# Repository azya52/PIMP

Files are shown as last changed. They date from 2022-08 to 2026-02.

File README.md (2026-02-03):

# PIMP
Модуль памяти для "Электроника МК-90" на основе отладочной платы Raspberry Pi Pico.

**Возможности:**
- Простое копирование образов картриджей - при подключении к ПК модуль работает как флешка (1,8МБ);
- При подключении к МК-90 модуль монтирует autorun.bin или первый попавшийся образ и работает как обычный МПО/СМП (только на чтение);
- Поддержка (только на чтение) протокола [Genjitsu SMP](https://github.com/vladkorotnev/SMPEmu/tree/master/pdp) благодаря чему можно загрузить несколько образов и выбирать нужный из списка непосредственно на МК90.

**Что понадобится:**
- Сама отладочная плата Raspberry Pi Pico;
- Преобразователь логических уровней 4-х канальный (стоит копейки);
- Тактовая кнопка (для сброса смонтированного образа).

**Схема подключения:**

Красивая:
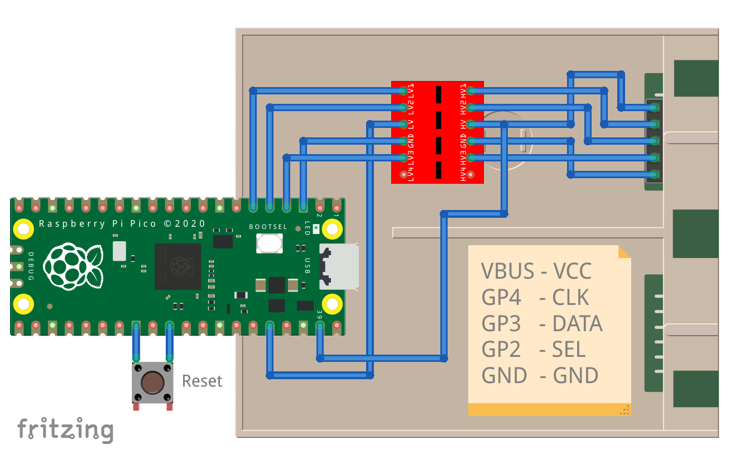
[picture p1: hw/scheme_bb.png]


Понятная:
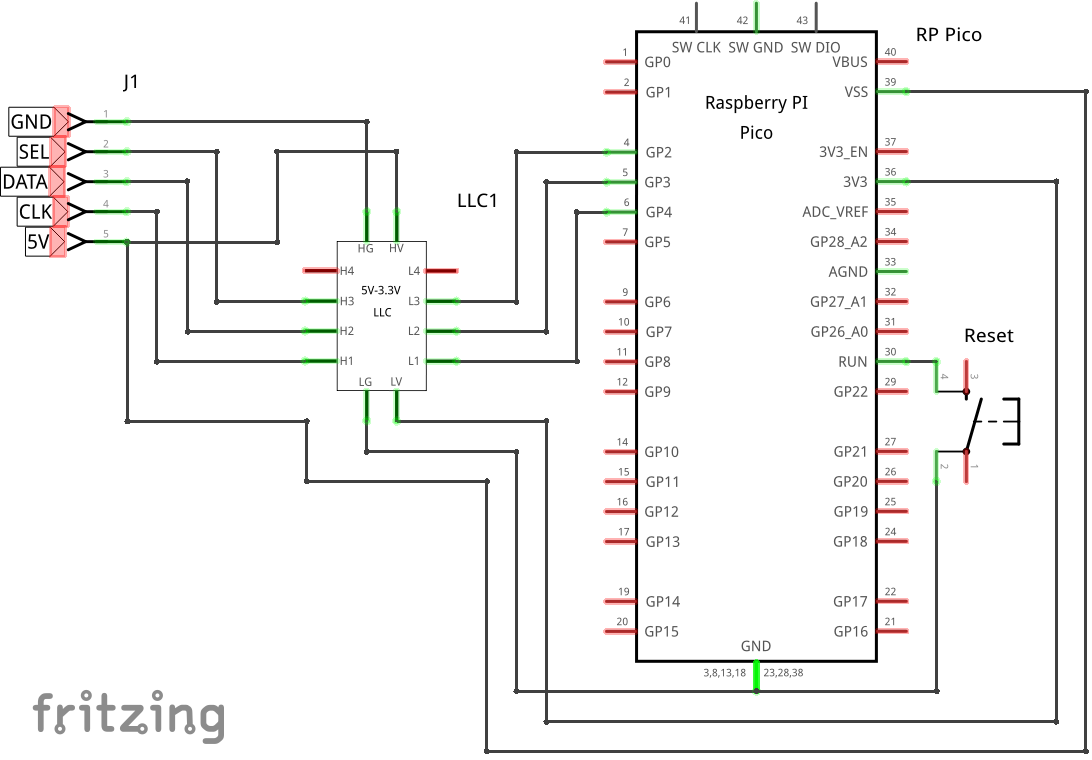
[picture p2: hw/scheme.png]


Для начала, нужно прошить Pico - для этого надо зажать единственную кнопку на плате, не отпуская ее подключить к ПК, плата определится как накопитель, на который копируем [pimp.uf2](/build/pimp.uf2). На этом прошивка закончена, модуль начнет определяться как Mass Storage Device, его нужно отформатировать в FAT с дефолтными параметрами, в итоге получится "флешка" на ~1,80МБ, на которую можно копировать образы. Если модуль отформатировался нормально и на него скопирован какой-либо образ, можно подключать его к МК-90 по указанной выше схеме.

Cхема относительно простая, хотя и есть одна проблема - МК-90 не любит нагрузку в выключенном состоянии (а при лучшем варианте Pico потребляет ~700мкА) поэтому, при разряженных батарейках, с подлюченным PIMP, МК-90 может не запускаться.

**Мультикартридж**

Для возможности выбора образа из нескольких непосредственно на МК-90, достаточно скопировать на модуль [загрузчик](https://github.com/vladkorotnev/SMPEmu/blob/master/pdp/autorun.bin) и конечно скопировать нужные образы.

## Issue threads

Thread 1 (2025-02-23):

Недочеты в PIMP

Bs0Dd, 2025-02-23:
Добрались у меня руки и до PIMP. Собрал себе в итоге два картриджа.

Первое с чем случилась пробема - с оригинальной схемой PIMP у меня глючил. Судя по всему, не хватало напряжения. По регламенту в МК90 на питание картриджа выдается 5в, в перерисовках петра указано 4.8. У меня же де-факто 4.5-4.6.
Не знаю, неисправность ли это (полупроводники уже могут быть "не те"), или так с завода. Сам по себе МК спокойно работает.

Проблема ушла при питании Pico от внешнего источника, но вот после десятка перетыканий между МК и ПК модуль Pico взял и выгорел (кз по питанию). Второй модуль вскоре аналогичным образом постигла та же учесть. Видимо диодно-резисторный согласователь такое не допускает (не эксперт - не знаю).

В итоге купил себе пару платок логических преобразователей (4 канальные) и собрал на них.
И от МК90 все работает (даже два модуля сразу), и сбоев никаких нет, да и компактнее вышло.

https://youtu.be/LFA96dhfLsM

Но, обнаружилась пара странных проблем, смахивающих уже на программные:

1. Монтирование образов (через Genjitsu) вызывает сбои, если на модуле больше 4 файлов (загрузчик + 3 образа). Стоит удалить любой "лишний" файл (чтобы их снова стало 4), монтирование начинает исправно работать. Добавляем 1 файл - после перезагрузки (когда указано имя файла) загорается светодиод ("ошибка"). Возможно что-то не так с драйвером ФС.
2. Если загрузить сборник Цветотроновских игр, с него не удается запустить игры/обучалки с последней страницы обоих списков. Такое ощущение, что после отгрузки этих последних страниц в эмуляторе происходит ошибка. После этого если вернуться в главное меню - не удастся открыть ни один из списков (сразу звуковой сигнал и возврат в меню), а если вернуться в меню загрузки - с СМП уже не получится загрузиться. Но что странно, светодиод ошибки при этом не горит...

Ну и еще проблема, очевидно, не связанная с эмулятором, но хотелось бы уточнить, не у одного ли у меня так.
Если запускать Цветотроновские игры со сборника, то в те моменты, когда у звука должна быть пауза, вместо нее присутствует какое-то странное жужжание в динамике. При этом если те же игры запустить с раздельных образов от Петра, жужжания нет. Может конечно дело в том, что сборник рассчитан на систему с BASIC 2.0, и лезет к какой-то системной подпрограмме, а у 1.0 не совсем те адреса, и Петр в раздельных образах это поправил...

https://youtu.be/3ItyVBS-i8Q

Bs0Dd, 2025-02-26:
Ну вот у меня почему-то никак не хочет больше 4 файлов нормально обрабатывать.
https://youtu.be/4b7dEg6dZbM

STMP бы попробовать, но с ним вот тоже возникли неполадки, issue оставлял еще перед этим.

Кстати, известо ли как частота обновления экрана задается? У Петра этот регистр толком не описан, в эмуляторе соответственно тоже не реализован.

azya52, 2025-02-27:
Постараюсь на днях проверить.
Частота задается через регистр $E802 описанный в таблице 2 даташита - https://web.archive.org/web/20200929094034/http://www.pisi.com.pl/piotr433/manuals/1835vg3.htm

Bs0Dd, 2025-03-26:
Нашел причину проблем с Цветотроновским сборником.
Перед отображением каждой страницы каталога и разных частей памяти вычитываются, видимо, заголовки (особо не вникал, для дела не важно).
И как раз при вычитке последних страниц каталогов (что у игр, что у обучашек) алгоритм чтения пытается вычитать диапазон 0x30000-0x30050, а картридж кончается на 0x2FFFF.

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

Для оригинального СМП это конечно не проблема, он (по идее) просто будет отдавать FF, но у PIMP, кажется, нет проверки на выход за границы образа - вот его и "накрывает". Если расширить образ, дописав в конец FF или 00, проблема исчезает и программы с последних страниц каталогов успешно загружаются.

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

Насчет жужжания в паузах при проигрывании музыки: оказывается там немного более веселая ситуация, но Петр действительно патчил игры при разделении их на образы к МПО-10. Я применил эти патчи в образ сборника и проблема исчезла, надо будет выложить его, как еще пару полезных патчей оттестирую.

P.S. писал пару дней назад на почту по поводу пары других проблем. В том числе с Птичкой на PIMP. Когда модуль вставлен в нулевой отсек, после загрузки игры загорается индикатор ошибки и модуль надо перевставлять. При первом отсеке такой проблемы нет. Пока не выяснял, в чем причина, но видимо после загрузки (загорается примерно сразу с появлением заставки) посылается какой-то неправильный запрос в СМП.

Bs0Dd, 2025-04-17:
Проблема с монтированием образов действительно оказалась НЕ связана с PIMP.

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

Загрузчик Genjitsu при передаче пути тестировал на нуль не байт, а слово, поэтому, перескакивал через него и продолжал транслировать ошметки загруженного списка файлов (буфер на все один), что, видимо и приводило к ошибке в СМП. А поскольку чем больше файлов, тем длиннее список и тем больше передается мусора, видимо это и влияло на сбои.

Переработал загрузчик (и в добавок написал софт для программирования оригинальных МПО-10 с помощью PIMP/STMP), поисправлял другие косячки, недочеты, добавил пару фишек. Проблема меня более не преследует.

Все остальное остается актуальным (касаемо сбоя со сборником игр и птичкой).

Насчет птички:

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

Похоже что этот кусок кода провоцирует отправку команды 0 на нулевой слот СМП, и если на нем находится PIMP (даже если игру запустить с МПО-10 в первом слоте), он эту команду считает за некорректную и уходит в состояние ошибки. Не вникал для чего именно он нужен, но в идеале бы тогда в неотладочной прошивке сделать игнор невалидных для PIMP команд (подобно ВГ2), вместо зацикливания в ошибке.

azya52, 2025-05-01:
Извините, что опять пропал - тяжело вернутся к проекту который уже отпустил) Теперь понятно почему я не ловил эту ошибку - я обычно переименовывал название образов в 1-2 буквы чтобы долго не печатать. Я постараюсь все же заставить себя и разобраться с этими ошибками. Спасибо за проделанную работу!

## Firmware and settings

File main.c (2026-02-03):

#include "tusb.h"
#include "fatfs/ff.h"
#include "main.h"
#include "stdlib.h"
#include "hardware/pll.h"
#include "hardware/clocks.h"
#include "hardware/structs/xip_ctrl.h"
#include "hardware/structs/syscfg.h"
#include "hardware/adc.h"
#include "hardware/rosc.h"
#include "hardware/xosc.h"
#include "mk90.pio.h"

FATFS FATFS_Obj;
FIL	appFile;
char fileList[256][12+1];
uint8_t	readBuffer;
PIO pio;
uint32_t sm_tx;
uint32_t sm_rx;

static void pio_irq(void);

static void error_handler(void) {
    while(1) {
        gpio_xor_mask(0x01 << PIN_LED);
        busy_wait_ms(255);
	}
}

static void clocks_initialize(void) {  
    // Enable the xosc
    xosc_init();

    // Before we touch PLLs, switch sys and ref cleanly away from their aux sources.
    hw_clear_bits(&clocks_hw->clk[clk_sys].ctrl, CLOCKS_CLK_SYS_CTRL_SRC_BITS);
    while (clocks_hw->clk[clk_sys].selected != 0x1) tight_loop_contents();

    pll_init(pll_usb, 1, 768 * MHZ, 4, 4);
    pll_deinit(pll_sys);

    clock_configure(clk_sys,
                    CLOCKS_CLK_SYS_CTRL_SRC_VALUE_CLKSRC_CLK_SYS_AUX,
                    CLOCKS_CLK_SYS_CTRL_AUXSRC_VALUE_CLKSRC_PLL_USB,
                    48 * MHZ,
                    48 * MHZ);

    clock_configure(clk_usb,
                    0, // No GLMUX
                    CLOCKS_CLK_USB_CTRL_AUXSRC_VALUE_CLKSRC_PLL_USB,
                    48 * MHZ,
                    48 * MHZ);

    clock_configure(clk_adc,
                    0, // No GLMUX
                    CLOCKS_CLK_ADC_CTRL_AUXSRC_VALUE_CLKSRC_PLL_USB,
                    48 * MHZ,
                    48 * MHZ);

    clock_stop(clk_ref);
    clock_stop(clk_peri);
    clock_stop(clk_rtc);
    clock_stop(clk_gpout0);
    clock_stop(clk_gpout1);
    clock_stop(clk_gpout2);
    clock_stop(clk_gpout3);

    clocks_hw->wake_en0 = ~(
        //CLOCKS_WAKE_EN0_CLK_SYS_VREG_AND_CHIP_RESET_BITS |
        CLOCKS_WAKE_EN0_CLK_SYS_RESETS_BITS |
        CLOCKS_WAKE_EN0_CLK_SYS_SPI0_BITS |
        CLOCKS_WAKE_EN0_CLK_PERI_SPI0_BITS |
        CLOCKS_WAKE_EN0_CLK_SYS_SPI1_BITS |
        CLOCKS_WAKE_EN0_CLK_PERI_SPI1_BITS |
        CLOCKS_WAKE_EN0_CLK_SYS_ROSC_BITS |
        CLOCKS_WAKE_EN0_CLK_SYS_PLL_SYS_BITS |
        CLOCKS_WAKE_EN0_CLK_SYS_PWM_BITS |
        CLOCKS_WAKE_EN0_CLK_SYS_PIO1_BITS |
        CLOCKS_WAKE_EN0_CLK_SYS_JTAG_BITS |
        CLOCKS_WAKE_EN0_CLK_SYS_I2C0_BITS |
        CLOCKS_WAKE_EN0_CLK_SYS_I2C1_BITS |
        CLOCKS_WAKE_EN0_CLK_SYS_RTC_BITS |
        CLOCKS_WAKE_EN0_CLK_RTC_RTC_BITS |
        CLOCKS_WAKE_EN0_CLK_SYS_DMA_BITS
    );

    clocks_hw->wake_en1 = ~(
        CLOCKS_WAKE_EN1_CLK_SYS_WATCHDOG_BITS |
        CLOCKS_WAKE_EN1_CLK_SYS_UART0_BITS |
        CLOCKS_WAKE_EN1_CLK_PERI_UART0_BITS |
        CLOCKS_WAKE_EN1_CLK_SYS_UART1_BITS |
        CLOCKS_WAKE_EN1_CLK_PERI_UART1_BITS |
        CLOCKS_WAKE_EN1_CLK_SYS_TBMAN_BITS |
        CLOCKS_WAKE_EN1_CLK_SYS_TIMER_BITS |
        CLOCKS_WAKE_EN1_CLK_SYS_SYSINFO_BITS
    );
    
}

static void dormant_goto_and_comeback(void) {
    uint32_t intstatus = save_and_disable_interrupts();
    gpio_set_dormant_irq_enabled(PIN_SELECT, IO_BANK0_DORMANT_WAKE_INTE0_GPIO0_EDGE_LOW_BITS, true);

    // Turn off flash
    xip_ctrl_hw->ctrl |= XIP_CTRL_POWER_DOWN_BITS;
    // Turn off SRAMs
    syscfg_hw->mempowerdown =
        0x00000020 | //SRAM5
        0x00000010 | //SRAM4
        0x00000080 | //USB
        0x00000040; //ROM

    // Before we touch PLLs, switch sys and ref cleanly away from their aux sources.
    hw_clear_bits(&clocks_hw->clk[clk_sys].ctrl, CLOCKS_CLK_SYS_CTRL_SRC_BITS);
    while (clocks_hw->clk[clk_sys].selected != 0x1) tight_loop_contents();
    pll_deinit(pll_sys);
    pll_deinit(pll_usb);

    // Sleep
    xosc_dormant();

    // Turn on SRAMs
    syscfg_hw->mempowerdown = 0;
    // Turn on flash
    xip_ctrl_hw->ctrl &= ~XIP_CTRL_POWER_DOWN_BITS;
    // Clear the irq so we can go back to dormant mode again if we want
    gpio_acknowledge_irq(PIN_SELECT, IO_BANK0_DORMANT_WAKE_INTE0_GPIO0_EDGE_LOW_BITS);
    // Restore clocks
    clocks_initialize();
    restore_interrupts(intstatus);
}

static void adc_irq(void) {
    uint16_t value = adc_fifo_get();
    if ((value > 0) && (value < ADC_4V2_THRESH)) {
        dormant_goto_and_comeback();
    }
}

static inline void adc_initialize(void) {
    adc_init();
	adc_gpio_init(29);
	adc_select_input(3);	// start with measurement for GPIO29 - IP Used in ADC mode (ADC3) to measure VSYS/3
	adc_fifo_setup(true, false, 1, true, false);
	irq_set_exclusive_handler(ADC_IRQ_FIFO, adc_irq);
	adc_irq_set_enabled(true);
	irq_set_enabled(ADC_IRQ_FIFO, true);
    irq_set_priority(ADC_IRQ_FIFO, PICO_LOWEST_IRQ_PRIORITY);
	adc_set_clkdiv(65535);	// slowest possible 65535: 832 measurements / sec
	adc_run(true);
}

static inline void gpio_initialize(void) {
    gpio_pull_up(PIN_CLK);
    gpio_pull_up(PIN_SELECT);
    gpio_pull_up(PIN_DATA);

    gpio_init(PIN_SELECT);
    gpio_init(PIN_VBUS);
    gpio_init(PIN_LED);

    gpio_set_dir(PIN_VBUS, GPIO_IN);
    gpio_set_dir(PIN_LED, GPIO_OUT);
    gpio_set_dir(PIN_SELECT, GPIO_IN);
}

static inline void pio_initialize(void) {
    pio = pio0;
    sm_tx = pio_claim_unused_sm(pio, true);
    sm_rx = pio_claim_unused_sm(pio, true);
    mk90bus_program_init(pio, sm_tx, sm_rx);
    
    irq_set_exclusive_handler(PIO0_IRQ_0, pio_irq);
    irq_set_enabled(PIO0_IRQ_0, true);
    pio_set_irq0_source_enabled(pio, pis_sm1_rx_fifo_not_empty, true);
    irq_set_priority(PIO0_IRQ_0, PICO_HIGHEST_IRQ_PRIORITY);
}

FRESULT openFile(char *filename) {
    DIR dj;
    FILINFO fno;
    FRESULT fr;

    f_close(&appFile);

    fr = f_opendir(&dj, "");
    if (fr == FR_OK) {
		uint32_t i = 0;
		do {
			fr = f_readdir(&dj, &fno);
			if (fr == FR_OK && (strcmp(fno.fname, "AUTORUN.BIN") != 0) && !(fno.fattrib & AM_DIR)) {
				strcpy(fileList[i++], fno.fname);
			}
		} while (fr == FR_OK && i < 255 && fno.fname[0] != 0);
		f_closedir(&dj);
    }

    if (filename != NULL) {
    	fr = f_open(&appFile, filename, FA_READ);
    }

    if (fr != FR_OK && fileList[0]) {
    	fr = f_open(&appFile, fileList[0], FA_READ);
    }
 
    if (fr == FR_OK) {
        uint32_t lktbl[256];
		lktbl[0] = 256;
        appFile.cltbl = lktbl;
		fr = f_lseek(&appFile, CREATE_LINKMAP);
	}

    return fr;
}

static void remount(void) {
    if (f_mount(&FATFS_Obj, "0", 1) == FR_OK) {
        openFile("AUTORUN.BIN");
    }
}

static inline void parseCommand(uint32_t command) {
    switch(command) {
        case 0x18:
        case 0x10: // read postdecrement
        case 0xD8:
        case 0xD0: {// read postincrement
                do {
                    pio_sm_put(pio, sm_tx, readBuffer << 24);
                    if ((command & 0xC0) == 0) f_lseek(&appFile, appFile.fptr-2); // postdecrement
                    f_read_byte(&appFile, &readBuffer);
                    while (!pio_interrupt_get(pio, SENDED_IRQ)) tight_loop_contents();
                } while(!gpio_get(PIN_SELECT));
                f_lseek(&appFile, appFile.fptr-2);
                f_read_byte(&appFile, &readBuffer);
            }
            break;

        case 0x00: // query status
            pio_sm_put(pio, sm_tx, 0x00 << 24);
            while (!pio_interrupt_get(pio, SENDED_IRQ) || !gpio_get(PIN_SELECT)) tight_loop_contents();
            break;

        case 0xA8: // set 24b address
            f_lseek(&appFile, mk90bus_read24(pio, sm_rx));
            f_read_byte(&appFile, &readBuffer);
            break;

        case 0xA0: // set 16b address
            f_lseek(&appFile, mk90bus_read16(pio, sm_rx));
            f_read_byte(&appFile, &readBuffer);
            break;

        case 0xF0: { // Genjitsu: get files list
            uint32_t i = 0;
            while (fileList[i][0]) {
                uint32_t j = 0;
                do {
                    pio_sm_put(pio, sm_tx, fileList[i][j] << 24);
                    while (!pio_interrupt_get(pio, SENDED_IRQ)) tight_loop_contents();
                } while (fileList[i][j++]);
                i++;
            }
            pio_sm_put(pio, sm_tx, 0xFF << 24);
            while (!pio_interrupt_get(pio, SENDED_IRQ) || !gpio_get(PIN_SELECT)) tight_loop_contents();
            }
            break;

        case 0xF1: { // Genjitsu: mount selected file
                char filename[12+1] = {0,};
                uint32_t i = 0;
                do {
                    filename[i] = mk90bus_read8(pio, sm_rx);
                } while (filename[i] && ++i < 13);
                if (openFile(filename) != FR_OK) {
                    error_handler();
                }
            }
            break;
            
        case 0xF2: // Genjitsu: unmount current file and go to the autorun
            remount();
            break;

        default: // unknown command - just ignore
            break;
    }
}

static void pio_irq(void) {   
    parseCommand(mk90bus_read8(pio, sm_rx));
    pio_sm_clear_fifos(pio, sm_rx);
    irq_clear(PIO0_IRQ_0);
}

int main(void) {
    gpio_initialize();
    rosc_disable();

    //Disable XIP Cache
	xip_ctrl_hw->ctrl &= ~XIP_CTRL_EN_BITS;

    //Sleep if USB VBUS isn't present
    if (!gpio_get(PIN_VBUS)) {
        dormant_goto_and_comeback();
    } else {
        clocks_initialize();
    }
    adc_initialize();
    pio_initialize();
    tusb_init();   
    remount();

    while (1) {
        __wfi();
        tud_task(); // tinyusb device task
    }
}

// Invoked when cdc when line state changed e.g connected/disconnected
void tud_cdc_line_state_cb(uint8_t itf, bool dtr, bool rts) {
    (void) itf;
    // connected
    if (dtr && rts) {
        tud_cdc_write_str("\r\nPIMP v1.1\r\n");
        tud_cdc_write_flush();
    }
}

uint32_t mount_str_pos = 0;
// Invoked when CDC interface received data from host
void tud_cdc_rx_cb(uint8_t itf) {
    while (tud_cdc_available()) {
        char chr = tud_cdc_n_read_char(itf);
        tud_cdc_write_char(chr);
        if ("MOUNT"[mount_str_pos++] != chr) {
            mount_str_pos = 0;
        }
        if (mount_str_pos == strlen("MOUNT")) {
            remount();
            tud_cdc_write_str("\r\nOK\r\n");
            mount_str_pos = 0;
        }
        tud_cdc_write_flush();
    }   
}

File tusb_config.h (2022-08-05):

/*
 * The MIT License (MIT)
 *
 * Copyright (c) 2019 Ha Thach (tinyusb.org)
 *
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
 */

#ifndef _TUSB_CONFIG_H_
#define _TUSB_CONFIG_H_

#ifdef __cplusplus
 extern "C" {
#endif

//--------------------------------------------------------------------
// COMMON CONFIGURATION
//--------------------------------------------------------------------

// defined by board.mk
#ifndef CFG_TUSB_MCU
  #error CFG_TUSB_MCU must be defined
#endif

// RHPort number used for device can be defined by board.mk, default to port 0
#ifndef BOARD_DEVICE_RHPORT_NUM
  #define BOARD_DEVICE_RHPORT_NUM     0
#endif

// RHPort max operational speed can defined by board.mk
// Default to Highspeed for MCU with internal HighSpeed PHY (can be port specific), otherwise FullSpeed
#ifndef BOARD_DEVICE_RHPORT_SPEED
  #if (CFG_TUSB_MCU == OPT_MCU_LPC18XX || CFG_TUSB_MCU == OPT_MCU_LPC43XX || CFG_TUSB_MCU == OPT_MCU_MIMXRT10XX || \
       CFG_TUSB_MCU == OPT_MCU_NUC505  || CFG_TUSB_MCU == OPT_MCU_CXD56)
    #define BOARD_DEVICE_RHPORT_SPEED   OPT_MODE_HIGH_SPEED
  #else
    #define BOARD_DEVICE_RHPORT_SPEED   OPT_MODE_FULL_SPEED
  #endif
#endif

// Device mode with rhport and speed defined by board.mk
#if   BOARD_DEVICE_RHPORT_NUM == 0
  #define CFG_TUSB_RHPORT0_MODE     (OPT_MODE_DEVICE | BOARD_DEVICE_RHPORT_SPEED)
#elif BOARD_DEVICE_RHPORT_NUM == 1
  #define CFG_TUSB_RHPORT1_MODE     (OPT_MODE_DEVICE | BOARD_DEVICE_RHPORT_SPEED)
#else
  #error "Incorrect RHPort configuration"
#endif

// This example doesn't use an RTOS
//#define CFG_TUSB_OS               OPT_OS_NONE

// CFG_TUSB_DEBUG is defined by compiler in DEBUG build
// #define CFG_TUSB_DEBUG           0

/* USB DMA on some MCUs can only access a specific SRAM region with restriction on alignment.
 * Tinyusb use follows macros to declare transferring memory so that they can be put
 * into those specific section.
 * e.g
 * - CFG_TUSB_MEM SECTION : __attribute__ (( section(".usb_ram") ))
 * - CFG_TUSB_MEM_ALIGN   : __attribute__ ((aligned(4)))
 */
#ifndef CFG_TUSB_MEM_SECTION
#define CFG_TUSB_MEM_SECTION
#endif

#ifndef CFG_TUSB_MEM_ALIGN
#define CFG_TUSB_MEM_ALIGN          __attribute__ ((aligned(4)))
#endif

//--------------------------------------------------------------------
// DEVICE CONFIGURATION
//--------------------------------------------------------------------

#ifndef CFG_TUD_ENDPOINT0_SIZE
#define CFG_TUD_ENDPOINT0_SIZE    64
#endif

//------------- CLASS -------------//
#define CFG_TUD_CDC              1
#define CFG_TUD_MSC              1
#define CFG_TUD_HID              0
#define CFG_TUD_MIDI             0
#define CFG_TUD_VENDOR           0

// CDC FIFO size of TX and RX
#define CFG_TUD_CDC_RX_BUFSIZE   (TUD_OPT_HIGH_SPEED ? 512 : 64)
#define CFG_TUD_CDC_TX_BUFSIZE   (TUD_OPT_HIGH_SPEED ? 512 : 64)


// MSC Buffer size of Device Mass storage
#define CFG_TUD_MSC_EP_BUFSIZE 4096

#ifdef __cplusplus
 }
#endif

#endif /* _TUSB_CONFIG_H_ */
